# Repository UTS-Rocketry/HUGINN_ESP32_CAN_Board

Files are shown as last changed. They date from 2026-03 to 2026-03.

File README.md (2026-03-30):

# CAN Logger
5b3f4bc4607f405ea5adb04bc922e155_T

A compact CAN bus logger and sniffer built for the Shingleback rocket. Built around the ESP32-C3 and SN65HVD230 transceiver, it sits on the CAN bus during ground support and pre-launch operations, streaming frames from the flight computer, sensor nodes, CAS board, and camera board over WiFi via MQTT for real-time monitoring.

## Overview

This board is designed for ground support and pre-launch monitoring of the Shingleback CAN bus. It passively sniffs CAN traffic and publishes decoded frames to an MQTT broker over WiFi, making it easy to verify system state, check sensor health, and monitor inter-board communication before launch.

## Hardware

| Component | Part |
|---|---|
| Microcontroller | ESP32-C3 |
| CAN Transceiver | SN65HVD230 |
| Power Input | 3.3V |

## Features

- CAN 2.0A/B frame capture
- Real-time publishing over WiFi via MQTT
- Passive monitoring, no interference with the CAN bus
- Compact form factor suitable for ground support equipment

## Monitored Systems

This board is intended to sniff traffic from the following Shingleback subsystems:

- Flight computer
- CAS board
- Camera board

## Status

Early prototype / bring-up phase. Not recommended for production use.

## License

MIT

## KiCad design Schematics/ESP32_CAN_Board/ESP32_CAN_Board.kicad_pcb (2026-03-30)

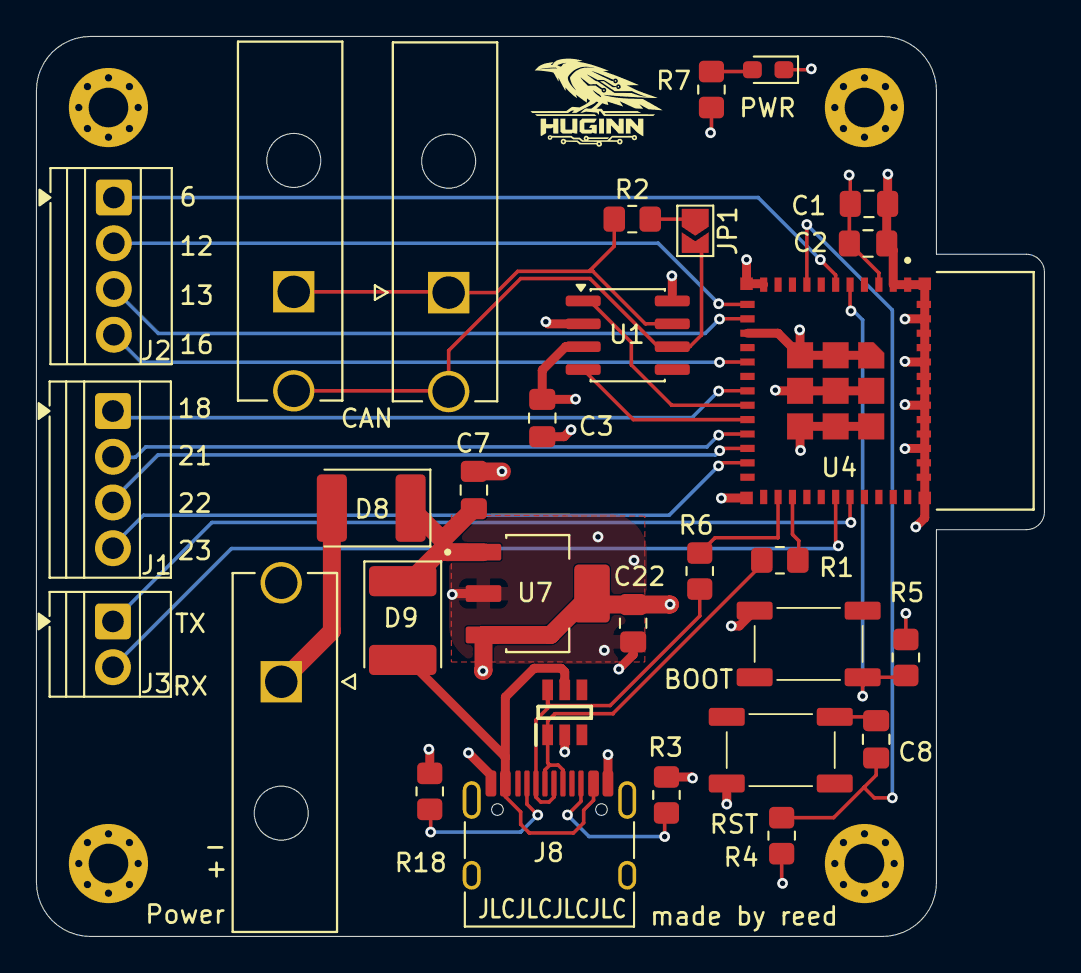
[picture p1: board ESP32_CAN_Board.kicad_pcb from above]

Board: 4 copper layers, 56.0 x 50.0 mm, 31 parts (0 on the bottom side), 30 nets.

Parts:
BootSwitch1: SAMZO G4R0015010
C1, C3, C8: 100nf; C_0805_2012Metric_Pad1.18x1.45mm_HandSolder
C2, C7: 1u; C_0805_2012Metric_Pad1.18x1.45mm_HandSolder
C22: 4.7u; C_0805_2012Metric_Pad1.18x1.45mm_HandSolder
CAN_IN1: CAN; MOLEX_26013114
CAN_OUT1: CAN; MOLEX_26013114
D8, D9: D_Schottky; D_2114_3652Metric
D21: SRV05-4.TCT; SOT95P280X145-6N
J1, J2: Screw_Terminal_01x04; TerminalBlock_Xinya_XY308-2.54-4P_1x04_P2.54mm_Horizontal
J3: Screw_Terminal_01x02; TerminalBlock_Xinya_XY308-2.54-2P_1x02_P2.54mm_Horizontal
J8: USB_C_Receptacle; USB_C_Receptacle_HRO_TYPE-C-31-M-12
JP1: SolderJumper_2_Open; SolderJumper-2_P1.3mm_Open_TrianglePad1.0x1.5mm
PowerIn1: 2 pin Molex; MOLEX_26013114
PowerLED1: RLED; LED_0603_1608Metric_Pad1.05x0.95mm_HandSolder
R1, R6: 27r; R_0805_2012Metric_Pad1.20x1.40mm_HandSolder
R2: 120r; R_0805_2012Metric_Pad1.20x1.40mm_HandSolder
R3, R18: 5.1k; R_0805_2012Metric_Pad1.20x1.40mm_HandSolder
R4, R5: 10k; R_0805_2012Metric_Pad1.20x1.40mm_HandSolder
R7: 1k; R_0805_2012Metric_Pad1.20x1.40mm_HandSolder
RSTSwitch1: SAMZO G4R0015010
U1: SN65HVD230; SOIC-8_3.9x4.9mm_P1.27mm
U4: ESP32-C3-MINI-1-N4; XCVR_ESP32-C3-MINI-1-N4
U7: LDL1117-3.3; SOT230P700X180-4N

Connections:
+3.3V: BootSwitch1.1, C1.1, C2.1, C3.1, C22.1, R4.1, R7.2, U1.3 (VCC), U4.3 (3V3), U7.3 (Vout), U7.4 (Vout)
+BATT: D8.2 (A), PowerIn1.1
/CAN/CANH: CAN_IN1.1, CAN_OUT1.1, R2.1, U1.7 (CANH)
/CAN/CANL: CAN_IN1.2, CAN_OUT1.2, JP1.2 (B), U1.6 (CANL)
/CAN/CAN_RX_2: U1.4 (R), U4.20 (IO6)
/CAN/CAN_TX_2: U1.1 (D), U4.19 (IO5)
/MCU/BOOT0: BootSwitch1.4, R5.2, U4.5 (IO2)
/MCU/D+: R1.1, U4.27 (IO19)
/MCU/D-: R6.1, U4.26 (IO18)
/MCU/NRST: C8.1, R4.2, U4.8 (EN)
/MCU/Pin6: J2.1, U4.6 (IO3)
/MCU/Pin12: J2.2, U4.12 (IO0)
/MCU/Pin13: J2.3, U4.13 (IO1)
/MCU/Pin16: J2.4, U4.16 (IO10)
/MCU/Pin18: J1.1, U4.18 (IO4)
/USBC/D+: D21.1, J8.A6 (D+), J8.B6 (D+), R1.2
/USBC/D-: D21.6, J8.A7 (D-), J8.B7 (D-), R6.2
/USBC/ESP5vUSB: D9.2 (A), D21.5, J8.A4 (VBUS), J8.A9 (VBUS), J8.B4 (VBUS), J8.B9 (VBUS)
GND: C1.2, C2.2, C3.2, C7.2, C22.2, D21.2, J8.A1 (GND), J8.A12 (GND), J8.B1 (GND), J8.B12 (GND), PowerIn1.2, PowerLED1.1 (K), R3.2, R5.1, R18.2, RSTSwitch1.3, U1.2 (GND), U1.8 (Rs), U4.1 (GND), U4.2 (GND), U4.11 (GND), U4.14 (GND), U4.36 (GND), U4.37 (GND), U4.38 (GND), U4.39 (GND), U4.40 (GND), U4.41 (GND), U4.42 (GND), U4.43 (GND), U4.44 (GND), U4.45 (GND), U4.46 (GND), U4.47 (GND), U4.48 (GND), U4.49_1 (GND), U4.49_2 (GND), U4.49_3 (GND), U4.49_4 (GND), U4.49_5 (GND), U4.49_6 (GND), U4.49_7 (GND), U4.49_8 (GND), U4.49_9 (GND), U4.50 (GND), U4.51 (GND), U4.52 (GND), U4.53 (GND), U7.2 (GND)
unnamed: C8.2, RSTSwitch1.2
unnamed: C7.1, D8.1 (K), D9.1 (K), U7.1 (Vin)
unnamed: J1.2, U4.21 (IO7)
unnamed: J1.3, U4.22 (IO8)
unnamed: J1.4, U4.23 (IO9)
unnamed: J3.1, U4.31 (TXD0)
unnamed: J3.2, U4.30 (RXD0)
unnamed: J8.A5 (CC1), R18.1
unnamed: J8.B5 (CC2), R3.1
unnamed: JP1.1 (A), R2.2
unnamed: PowerLED1.2 (A), R7.1

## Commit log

2026-03-27 initial design completed
    [CAN.kicad_sch, ESP32_CAN_Board.kicad_pcb, ESP32_CAN_Board.kicad_sch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]
2026-03-27 finished ready for order
    [ESP32_CAN_Board.kicad_pcb, ESP32_CAN_Board.kicad_sch, MCU.kicad_sch]
2026-03-27 mcu schematic update
    [MCU.kicad_sch]
2026-03-30 final Draft Completed, In JLPCB Cart
    [CAN.kicad_sch, ESP32_CAN_Board.kicad_pcb, MCU.kicad_sch]
